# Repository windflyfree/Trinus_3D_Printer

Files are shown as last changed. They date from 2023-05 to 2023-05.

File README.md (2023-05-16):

By [WOWKI.COM](http://wowki.com)

我和我的朋友们在二手市场上买了一批Trinus打印机，这是一款七八年前的打印机，全新。看起来是抵货的机子。Trinus这家公司似乎已经倒闭，我们买的价格非常低，大概在60美金左右。主要看重的是Trinus的四个滑台，比较坚固，适合改造成为激光雕刻机或者CNC雕刻机。

经过一个多月的大家的尝试，最终我们搞懂了主板的引脚、klipper的配置、热床的转接（原主板不支持直接接热床，需要mos，我们设计了专用的转接pcb）、激光、cnc等，期待能有机会折腾出更多更有趣的玩法。

My friends and I bought a batch of Trinus printers at a second-hand market. They are brand new machines from 7-8 years ago which seem to be surplus stock. Trinus, the company appears to have gone out of business. We got them for a very low price, around $60 each. The main feature we were interested in was Trinus' four sturdy sliders, which are suitable for converting into laser engravers or CNC routers. After more than a month of trial and error, we finally figured out the pinouts of the main board and configured Klipper.

We designed a dedicated adapter PCB for the hotbed (the original mainboard did not support direct connection to the heated bed and required a MOS module), as well as for laser engraving, CNC, and more. We hope to have the opportunity to explore and discover even more interesting ways to play with these machines. After all, technology knows no borders, and neither does human happiness and joy.  



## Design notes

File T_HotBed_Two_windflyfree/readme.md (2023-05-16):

转接小板 BOM

| Quantity |	Comment	 | Designator | Footprint |	Value |	Manufacturer Part |
| --- | --- |--- | --- |--- | --- |
|1	|100nF	|C1|	C0805	|	|0805B104K500NT|
|1	|IN4148|	D?|	LL-34_L3.5-W1.5-RD|	|	IN4148|
|2|	VH-4A高弯|	P1,P2	|CONN-TH_4P-P3.96_VH3.96-4AWD |	|	VH-4A高弯|
|1|	IRLR7843|Q1 |	TO-252-2_L6.5-W6.1-P4.58-LS10.0-TR |	|	IRLR7843|
|1|	100Ω	|R1	|R0805	|100Ω|	0805W8F1000T5E|
|2|	10kΩ	|R2,R3	|R0805|	10kΩ	|0805W8F1002T5E|
|1|	EL357N(A)	|U1	|SOP-4_L4.4-W4.0-P2.54-LS7.0-TL |	|	EL357N(A)|

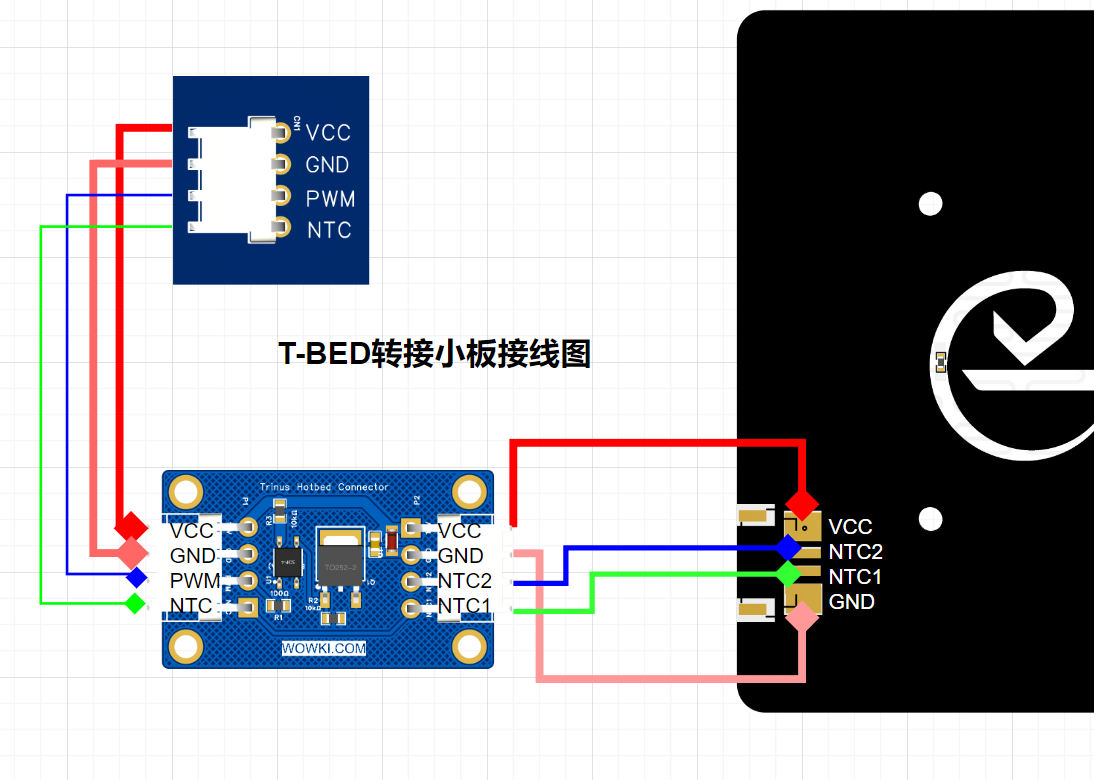
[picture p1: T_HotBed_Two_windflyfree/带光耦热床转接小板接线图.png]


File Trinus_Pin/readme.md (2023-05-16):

Trinus 1.3 pin

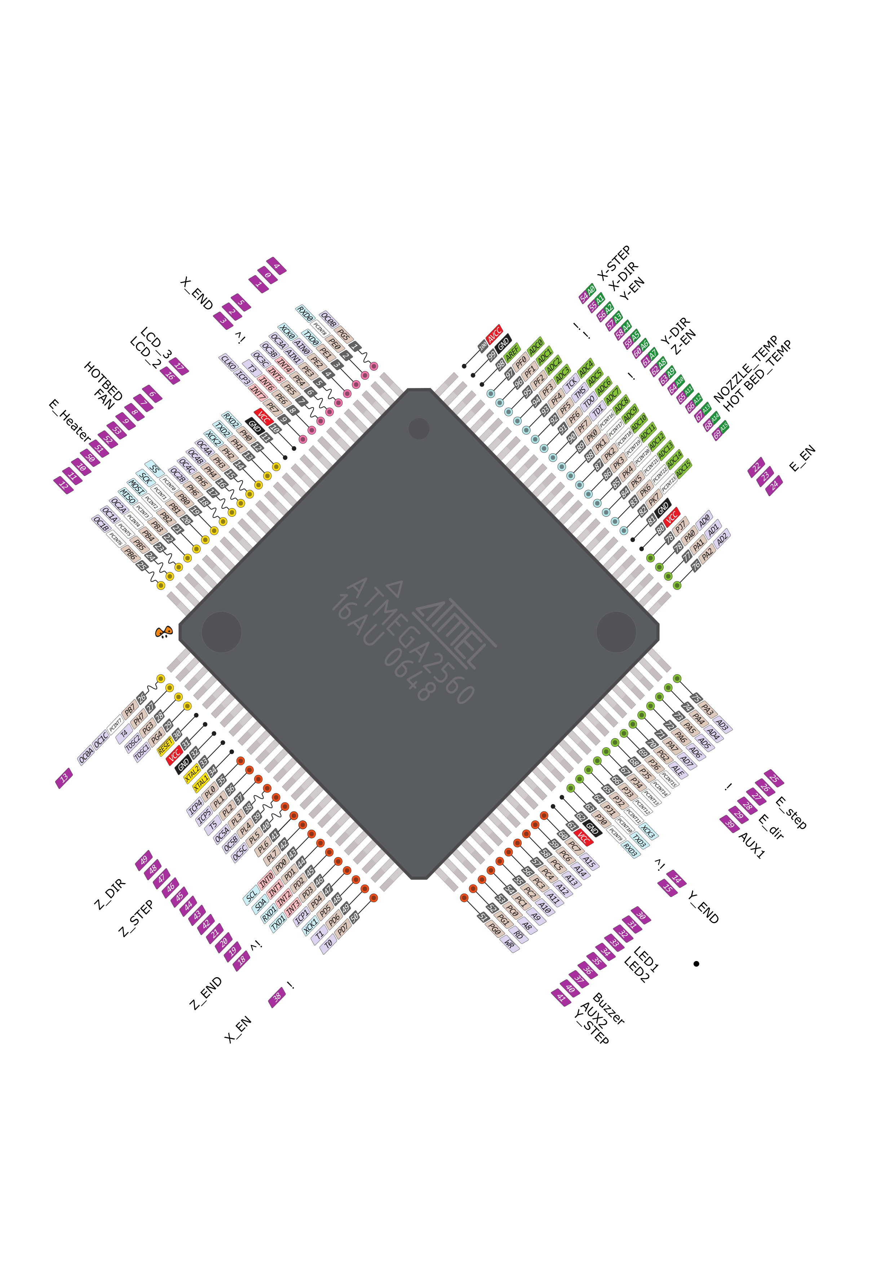
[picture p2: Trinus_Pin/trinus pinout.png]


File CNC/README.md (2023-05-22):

By [WOWKI.COM](http://wowki.com)

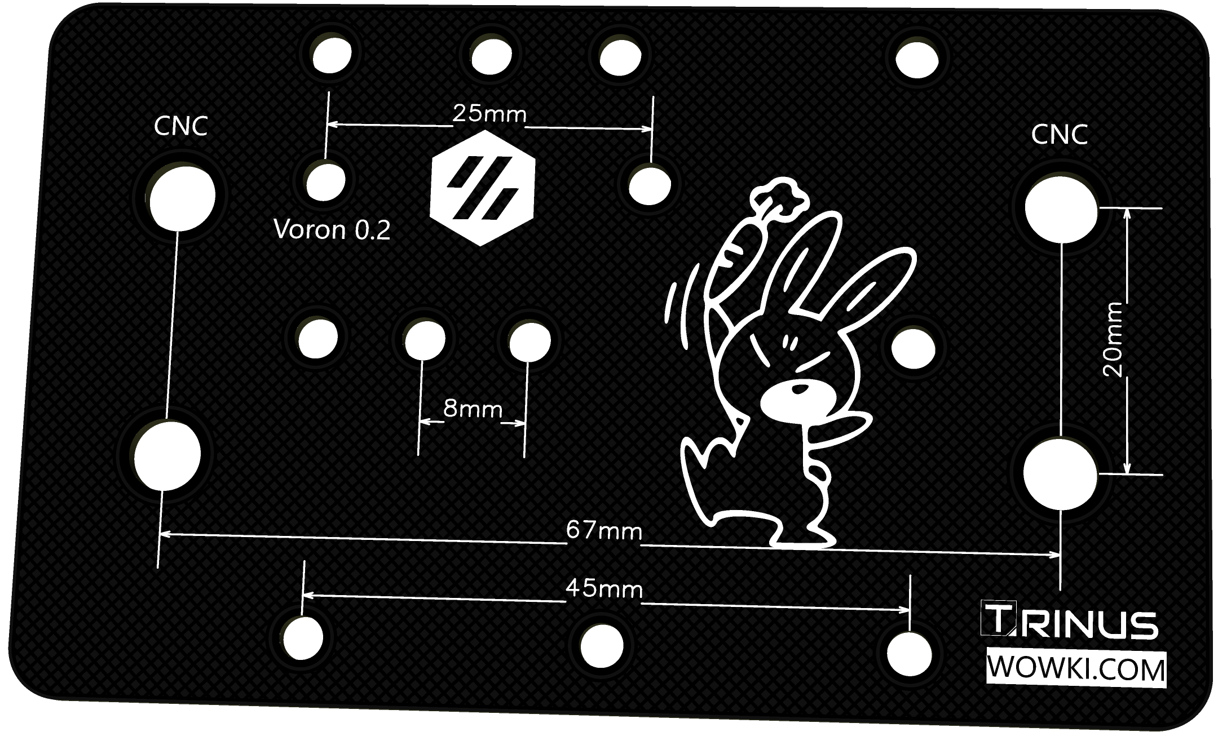
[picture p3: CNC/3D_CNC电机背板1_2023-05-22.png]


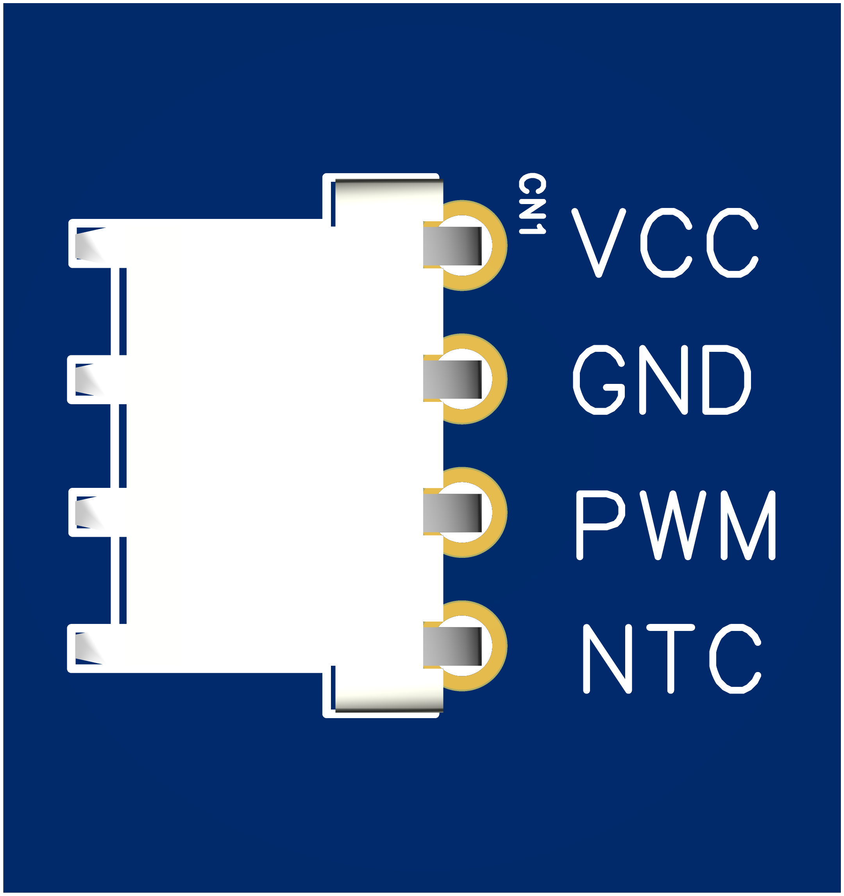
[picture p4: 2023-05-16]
PIC/3D_PCB9_2023-05-15.png

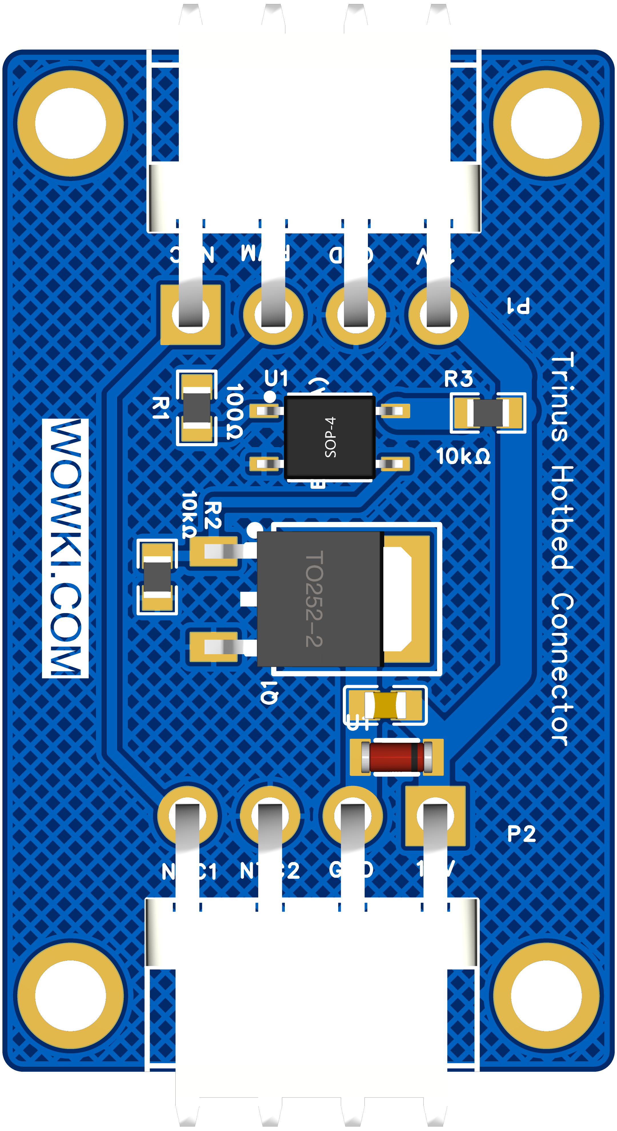
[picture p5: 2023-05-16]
PIC/3D_带光耦mos_1_2023-05-15.png

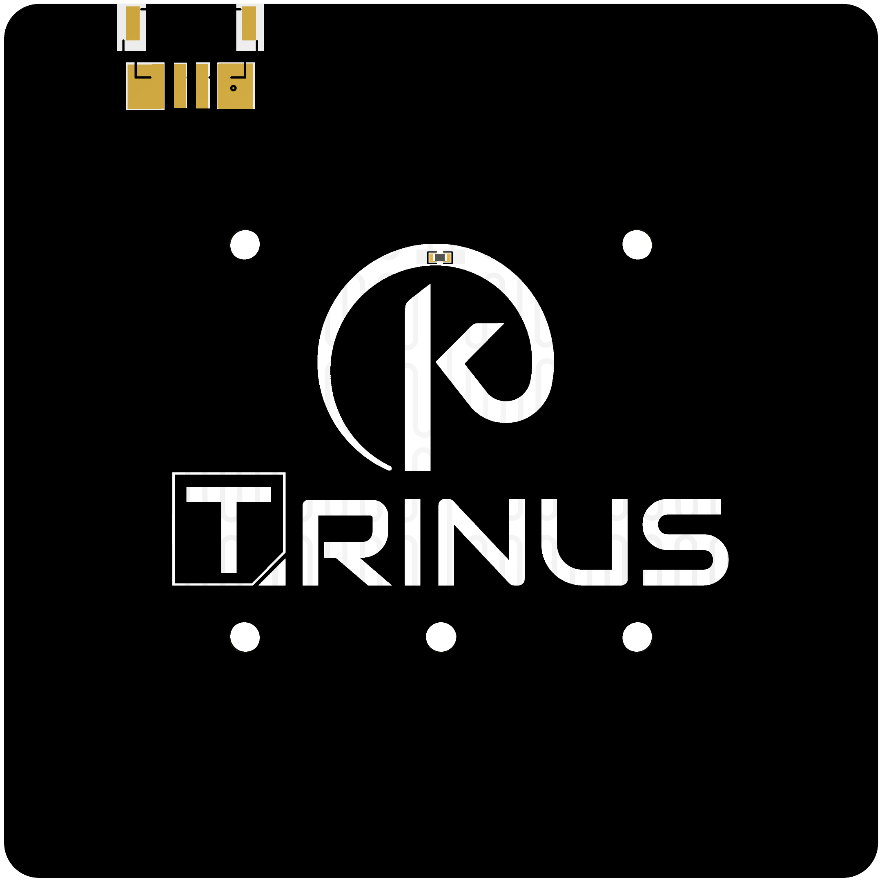
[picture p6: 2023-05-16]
PIC/3D_5孔10cm右插 修成线路错误_2023-05-15.png

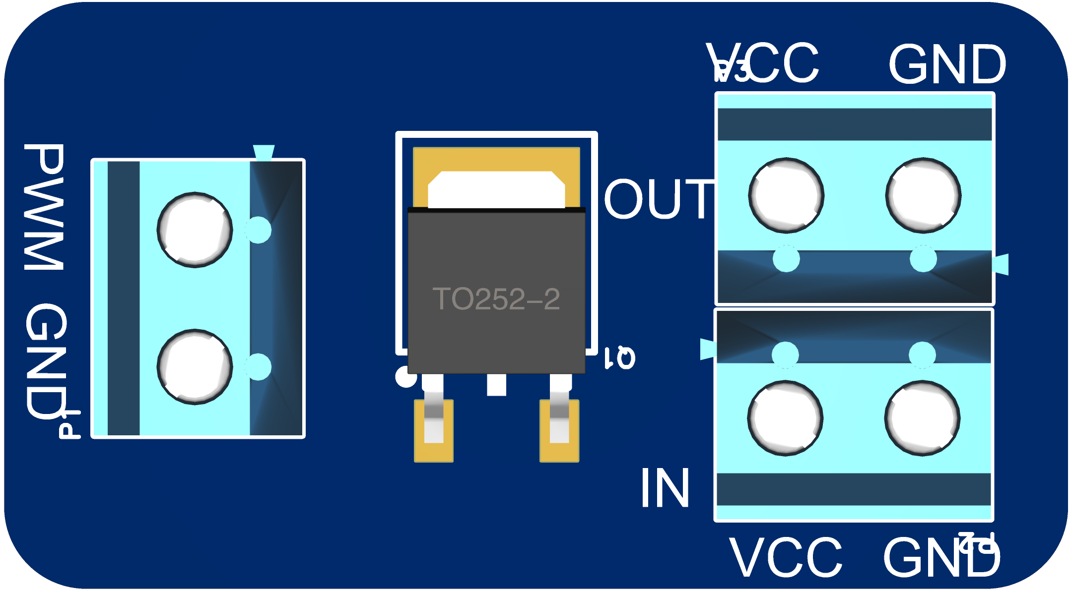
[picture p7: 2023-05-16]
PIC/MOS 3D_PCB9_2023-05-15.png

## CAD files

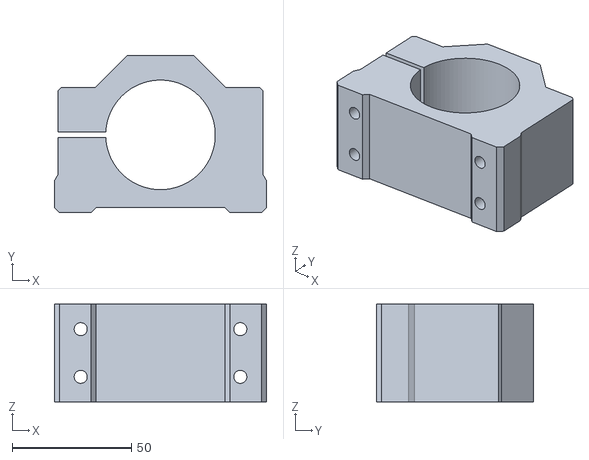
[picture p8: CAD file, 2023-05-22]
CNC/795电机抱座 v2.stl
89.0 x 66.0 x 41.0

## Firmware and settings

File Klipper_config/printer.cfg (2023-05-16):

[mcu]
serial: /dev/serial/by-id/usb-1a86_USB2.0-Serial-if00-port0

[virtual_sdcard]
path: /home/klipper/printer_data/gcodes

[include printer-macros.cfg]
[include mainsail.cfg] 
[include T_leds.cfg]

#[include timelapse.cfg]
#[exclude_object]

[display_status]

[printer]
kinematics: cartesian
max_velocity: 50
max_accel:500
max_z_velocity: 10
max_z_accel: 200
square_corner_velocity: 5

[stepper_x]
step_pin: PF0
dir_pin: !PF1
enable_pin: !PD7
microsteps: 16
rotation_distance: 14   ##rotation_distance = ((360°/1.8°) * microsteps) / 80 # # 旋转距离 = （圆周360°/步距角）*细分/每MM脉冲值
endstop_pin:^!PE5 #X-Min, PE4:X-Max
position_endstop: 0
position_max: 120
homing_speed: 30


[stepper_y]
step_pin: PG0
dir_pin: !PF7
enable_pin: !PF2
microsteps: 16
rotation_distance: 14
endstop_pin: ^!PJ1  #Y-Min, PJ0:Y-Max
position_endstop: 0
position_max: 120
homing_speed:30

[stepper_z]
step_pin: PL3
dir_pin: PL1
enable_pin: PK0
microsteps: 16
rotation_distance: 1.8
endstop_pin: ^!PD3  #Z-Min, PD2:Z-Max
position_endstop: 0
position_max: 120
position_min: 0
homing_speed: 10

[extruder]
step_pin: PA4
dir_pin: !PA6
enable_pin: PA2
microsteps: 16
rotation_distance: 13.2
gear_ratio: 3:1
nozzle_diameter: 0.4
filament_diameter: 1.750
pressure_advance = 0.11
heater_pin: PB4
sensor_type:Generic 3950
sensor_pin: PK5
min_temp: -255
max_temp: 250
#control: pid
#pid_Kp: 22.2
#pid_Ki: 1.08
#pid_Kd: 114

[firmware_retraction]
retract_length: 1.0
retract_speed: 40
unretract_extra_length: 0 # The length (in mm) of *additional* filament to add when unretracting.
unretract_speed: 40

[fan]
pin: PH6

[heater_bed]
heater_pin: PH5
sensor_type: Generic 3950
sensor_pin: PK6
min_temp: -255
max_temp:120
control = pid
pid_kp = 74.932
pid_ki = 1.230
pid_kd = 1140.844

[probe]
pin:PE4
x_offset:35
y_offset:15
z_offset:2
speed:30
samples:3
samples_result:median
sample_retract_dist:2.0
samples_tolerance:0.03
samples_tolerance_retries:3


[bed_mesh]
speed:30
horizontal_move_z:5
mesh_min: 35,20
mesh_max: 115,115
probe_count:3,3
algorithm:bicubic
fade_start:1
fade_end: 10
fade_target: 0

#[input_shaper]
#shaper_freq_x: 55.2
#shaper_freq_y: 35.4
#shaper_type: mzv

#*# <---------------------- SAVE_CONFIG ---------------------->
#*# DO NOT EDIT THIS BLOCK OR BELOW. The contents are auto-generated.
#*#
#*# [extruder]
#*# control = pid
#*# pid_kp = 19.907
#*# pid_ki = 0.582
#*# pid_kd = 170.209
#*#
#*# [bed_mesh default]
#*# version = 1
#*# points =
#*# 	-0.025375, 0.183875, 0.403812
#*# 	0.233937, 0.280062, 0.413937
#*# 	0.241812, -0.159250, 0.298062
#*# x_count = 3
#*# y_count = 3
#*# mesh_x_pps = 2
#*# mesh_y_pps = 2
#*# algo = bicubic
#*# tension = 0.2
#*# min_x = 35.0
#*# max_x = 115.0
#*# min_y = 20.0
#*# max_y = 115.0
#*#

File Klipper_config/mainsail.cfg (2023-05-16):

[virtual_sdcard]
path: /home/klipper/printer_data/gcodes

[pause_resume]

[display_status]

[gcode_macro CANCEL_PRINT]
description: Cancel the actual running print
rename_existing: CANCEL_PRINT_BASE
gcode:
#    status_ready
    TURN_OFF_HEATERS
    CANCEL_PRINT_BASE

[gcode_macro PAUSE]
description: Pause the actual running print
rename_existing: PAUSE_BASE
# change this if you need more or less extrusion
variable_extrude: 1.0
gcode:
   # status_part_ready
    LEDMAX

    ##### read E from pause macro #####
    {% set E = printer["gcode_macro PAUSE"].extrude|float %}
    ##### set park positon for x and y #####
    # default is your max posion from your printer.cfg
    {% set x_park = printer.toolhead.axis_maximum.x|float - 5.0 %}
    {% set y_park = printer.toolhead.axis_maximum.y|float - 5.0 %}
    ##### calculate save lift position #####
    {% set max_z = printer.toolhead.axis_maximum.z|float %}
    {% set act_z = printer.toolhead.position.z|float %}
    {% if act_z < (max_z - 2.0) %}
        {% set z_safe = 2.0 %}
    {% else %}
        {% set z_safe = max_z - act_z %}
    {% endif %}
    ##### end of definitions #####
    PAUSE_BASE
    G91
    {% if printer.extruder.can_extrude|lower == 'true' %}
      G1 E-{E} F2100
    {% else %}
      {action_respond_info("Extruder not hot enough")}
    {% endif %}
    {% if "xyz" in printer.toolhead.homed_axes %}
      G1 Z{z_safe} F900
      G90
      G1 X{x_park} Y{y_park} F3000
    {% else %}
      {action_respond_info("Printer not homed")}
    {% endif %} 
    
[gcode_macro RESUME]
description: Resume the actual running print
rename_existing: RESUME_BASE
gcode:
    status_busy
    ##### read E from pause macro #####
    {% set E = printer["gcode_macro PAUSE"].extrude|float %}
    #### get VELOCITY parameter if specified ####
    {% if 'VELOCITY' in params|upper %}
      {% set get_params = ('VELOCITY=' + params.VELOCITY)  %}
    {%else %}
      {% set get_params = "" %}
    {% endif %}
    ##### end of definitions #####
    {% if printer.extruder.can_extrude|lower == 'true' %}
      G91
      G1 E{E} F2100
    {% else %}
      {action_respond_info("Extruder not hot enough")}
    {% endif %}  
    RESUME_BASE {get_params}

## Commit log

2023-05-16 Create Using PWM tools
2023-05-16 Rename Using PWM tools to Using PWM tools.md
2023-05-16 Update buzzer.cfg, crowsnest.conf, and 38 more files...
    [TT_leds.cfg, T_leds.cfg, buzzer.cfg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]
2023-05-16 Update 5孔10cm右插35w.zip, readme.md, and 8 more files...
2023-05-16 Update 12.5.png, 12✘12.5 12v 50w热床.zip, and 2 more files...
2023-05-22 Update 3D_CNC电机背板1_2023-05-22.png, 795电机抱座 v2.stl, and 2 more files...
    [795电机抱座 v2.stl]
